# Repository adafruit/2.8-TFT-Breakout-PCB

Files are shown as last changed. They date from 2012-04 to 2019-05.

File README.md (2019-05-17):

# 2.8" TFT LCD Display Breakout PCBs
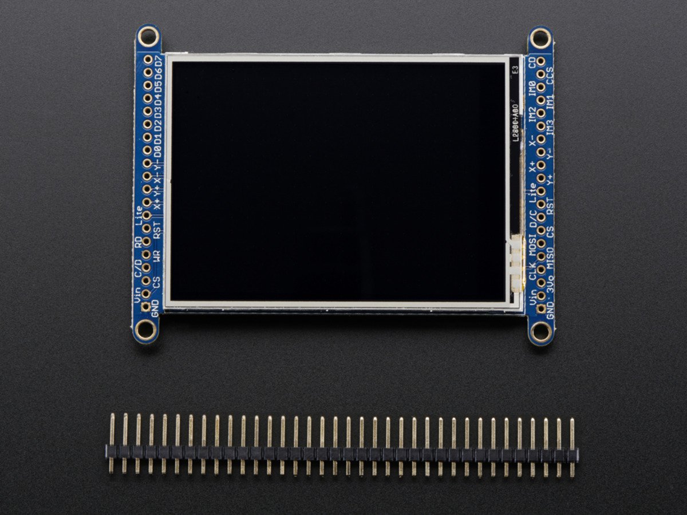
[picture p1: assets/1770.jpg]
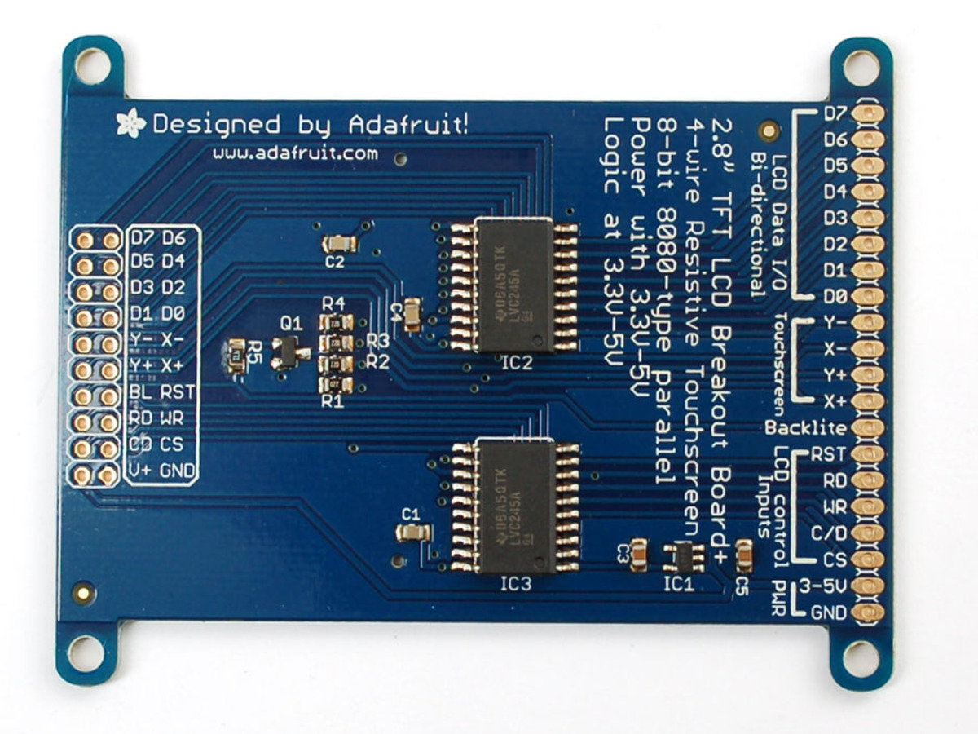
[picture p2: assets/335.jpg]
&nbsp; <br />
Click to view/purchase from the Adafruit Shop:
- [2.8" TFT LCD with Touchscreen Breakout Board w/MicroSD Socket - ILI9341](https://www.adafruit.com/product/1770)
- [2.8" 18-bit color TFT LCD with touchscreen breakout board - ILI9325](https://www.adafruit.com/product/335)

Add some jazz & pizazz to your project with a color touchscreen LCD. This TFT display is big (2.8" diagonal) bright (4 white-LED backlight) and colorful! 240x320 pixels with individual RGB pixel control, this has way more resolution than a black and white 128x64 display. As a bonus, this display has a resistive touchscreen attached to it already, so you can detect finger presses anywhere on the screen.

The ILI9325 screen has been discontinued, but the 2.8" ILI341 touchscreen breakout is nearly identical, having both an 8-bit and a SPI interface mode as well as a MicroSD card socket, all in the same form factor! 

Adafruit 2.8" 18-bit color TFT LCD displays with microSD card breakout

These are the Eagle CAD files for the Adafruit 2.8" 18-bit color TFT LCD display with microSD card breakouts:
  ----> https://www.adafruit.com/product/1770 (newer ILI9341 version)
  ----> https://www.adafruit.com/products/335 (older ILI9325 version)

### License

Adafruit invests time and resources providing this open source design, please support Adafruit and open-source hardware by [purchasing products from Adafruit](https://www.adafruit.com)!

All text above must be included in any redistribution

Designed by Limor Fried/Ladyada for Adafruit Industries.
Creative Commons Attribution/Share-Alike, all text above must be included in any redistribution. 
See license.txt for additional information.

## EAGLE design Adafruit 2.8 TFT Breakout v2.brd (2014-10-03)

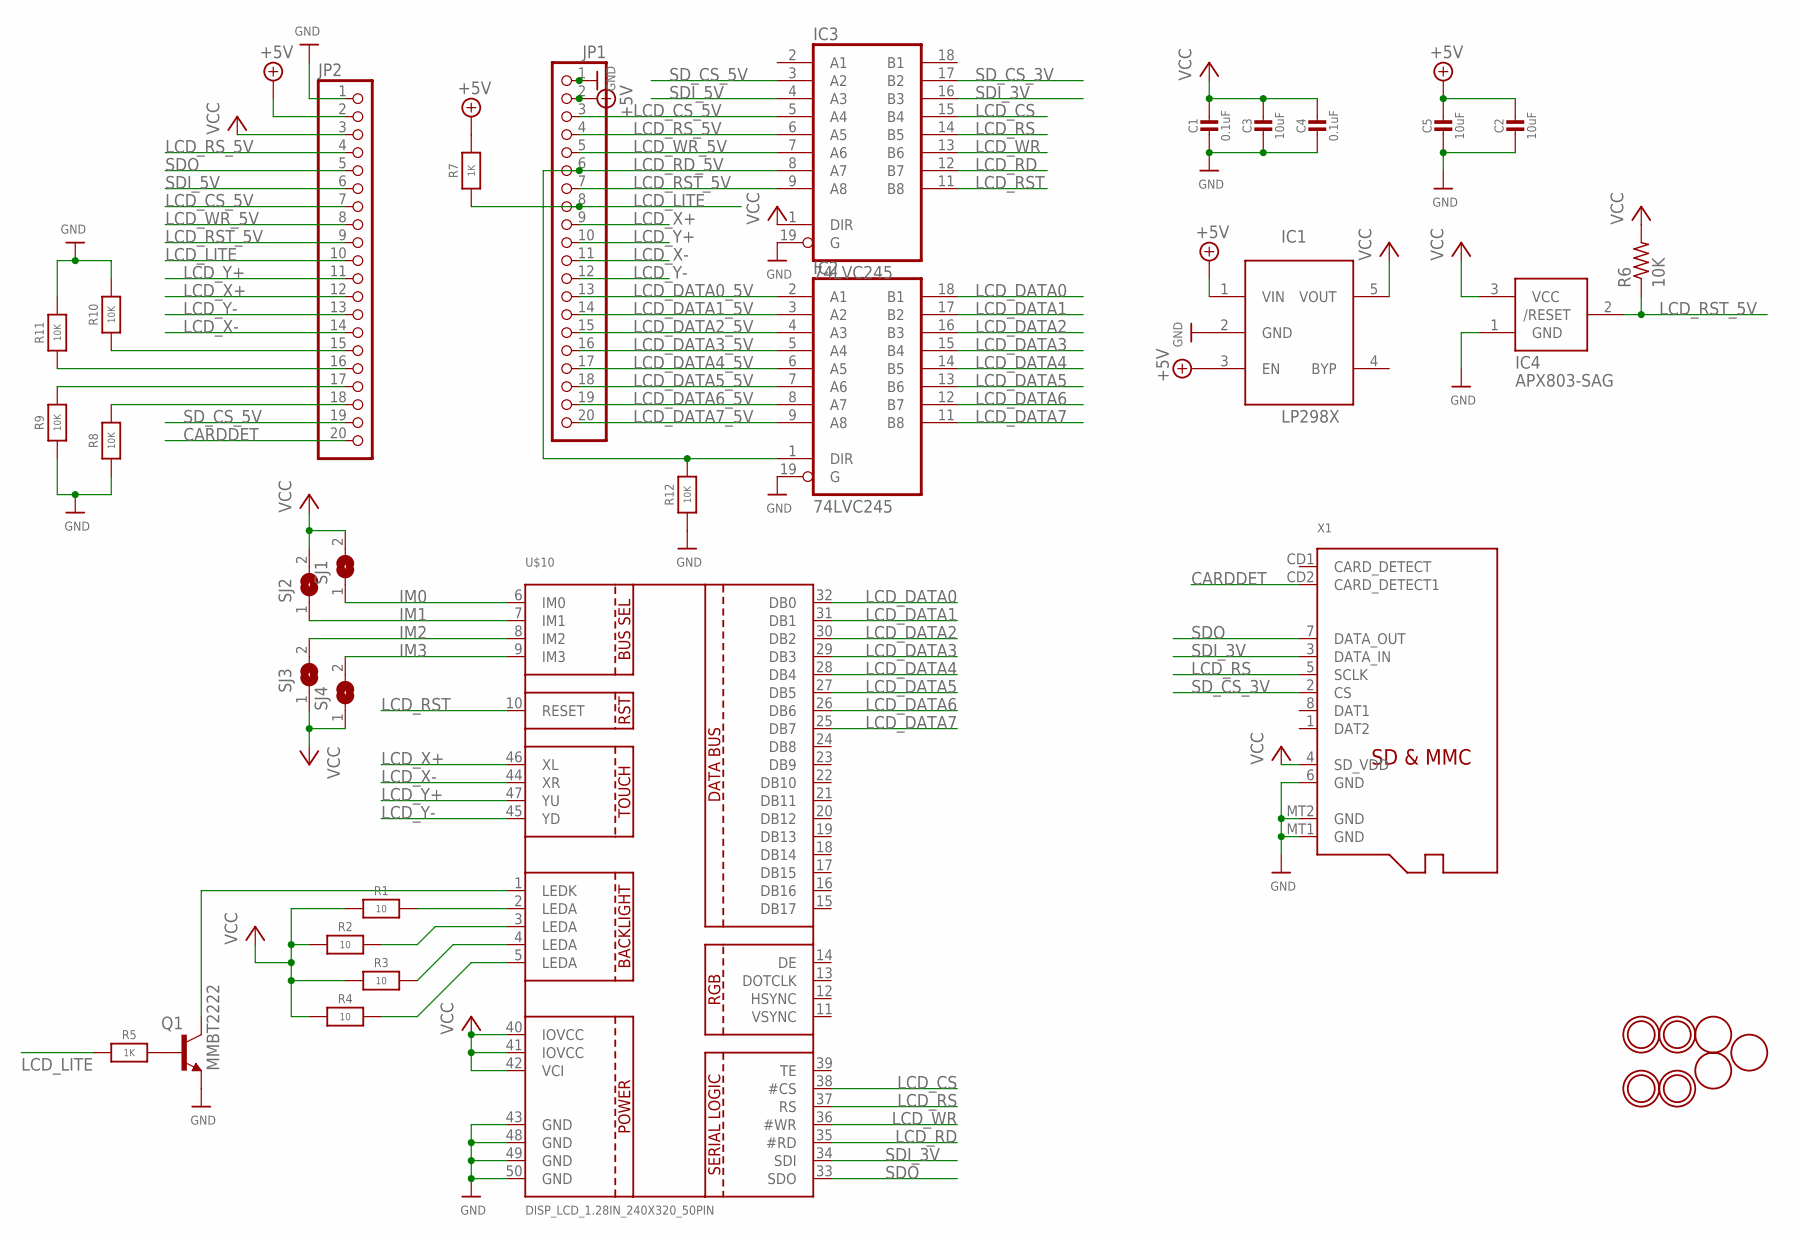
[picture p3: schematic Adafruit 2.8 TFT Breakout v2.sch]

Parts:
C1, C4: 0.1uF; 0805-NO
C2, C3, C5: 10uF; 0805-NO
IC1: MIC5225-3.3; SOT23-5L
IC2, IC3: 74LVC245; SO20W
IC4: APX803-SAG; SOT23
JP1, JP2: HEADER-1X20ROUND; 1X20_ROUND
Q1: MMBT2222; SOT23-BEC
R1, R2, R3, R4: 10; 0805-NO
R5, R7: 1K; 0805-NO
R6: 10K; R0805
R8, R9, R10, R11, R12: 10K; 0805-NO
SJ1, SJ2, SJ3, SJ4: SOLDERJUMPER; SOLDERJUMPER_ARROW_NOPASTE
U$7, U$15, U$16, U$17: MOUNTINGHOLE3.0THIN; MOUNTINGHOLE_3.0_PLATEDTHIN
U$9, U$11, U$23: FIDUCIAL; FIDUCIAL_1MM
U$10: DISP_LCD_1.28IN_240X320_50PIN; TFT_2.83IN_240X320_50PIN
X1: MICROSD

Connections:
+5V: C2.1, C5.1, IC1.1 (VIN), IC1.3 (EN), JP1.2, JP2.2, R7.2
CARDDET: JP2.20, X1.CD2 (CARD_DETECT1)
GND: C1.2, C2.2, C3.2, C4.2, C5.2, IC1.2 (GND), IC2.10 (GND), IC2.19 (G), IC3.10 (GND), IC3.19 (G), IC4.1 (GND), JP1.1, JP2.1, Q1.E, R8.1, R9.1, R10.2, R11.2, R12.1, U$10.43 (GND), U$10.48 (GND), U$10.49 (GND), U$10.50 (GND), X1.6 (GND), X1.MT1 (GND), X1.MT2 (GND)
IM0: JP2.18, R8.2, SJ1.1, U$10.6 (IM0)
IM1: JP2.17, R9.2, SJ2.1, U$10.7 (IM1)
IM2: JP2.16, R11.1, SJ3.2, U$10.8 (IM2)
IM3: JP2.15, R10.1, SJ4.2, U$10.9 (IM3)
LCD_CS: IC3.15 (B4), U$10.38 (#CS)
LCD_CS_5V: IC3.5 (A4), JP1.3, JP2.7
LCD_DATA0: IC2.18 (B1), U$10.32 (DB0)
LCD_DATA0_5V: IC2.2 (A1), JP1.13
LCD_DATA1: IC2.17 (B2), U$10.31 (DB1)
LCD_DATA1_5V: IC2.3 (A2), JP1.14
LCD_DATA2: IC2.16 (B3), U$10.30 (DB2)
LCD_DATA2_5V: IC2.4 (A3), JP1.15
LCD_DATA3: IC2.15 (B4), U$10.29 (DB3)
LCD_DATA3_5V: IC2.5 (A4), JP1.16
LCD_DATA4: IC2.14 (B5), U$10.28 (DB4)
LCD_DATA4_5V: IC2.6 (A5), JP1.17
LCD_DATA5: IC2.13 (B6), U$10.27 (DB5)
LCD_DATA5_5V: IC2.7 (A6), JP1.18
LCD_DATA6: IC2.12 (B7), U$10.26 (DB6)
LCD_DATA6_5V: IC2.8 (A7), JP1.19
LCD_DATA7: IC2.11 (B8), U$10.25 (DB7)
LCD_DATA7_5V: IC2.9 (A8), JP1.20
LCD_LITE: JP1.8, JP2.10, R5.1, R7.1
LCD_RD: IC3.12 (B7), U$10.35 (#RD)
LCD_RD_5V: IC2.1 (DIR), IC3.8 (A7), JP1.6, R12.2
LCD_RS: IC3.14 (B5), U$10.37 (RS), X1.5 (SCLK)
LCD_RST: IC3.11 (B8), U$10.10 (RESET)
LCD_RST_5V: IC3.9 (A8), IC4.2 (/RESET), JP1.7, JP2.9, R6.1
LCD_RS_5V: IC3.6 (A5), JP1.4, JP2.4
LCD_WR: IC3.13 (B6), U$10.36 (#WR)
LCD_WR_5V: IC3.7 (A6), JP1.5, JP2.8
LCD_X+: JP1.9, JP2.12, U$10.46 (XL)
LCD_X-: JP1.11, JP2.14, U$10.44 (XR)
LCD_Y+: JP1.10, JP2.11, U$10.47 (YU)
LCD_Y-: JP1.12, JP2.13, U$10.45 (YD)
unnamed: R4.2, U$10.5 (LEDA)
unnamed: R1.2, U$10.2 (LEDA)
unnamed: R2.2, U$10.3 (LEDA)
unnamed: R3.2, U$10.4 (LEDA)
unnamed: Q1.C, U$10.1 (LEDK)
unnamed: Q1.B, R5.2
SDI_3V: IC3.16 (B3), U$10.34 (SDI), X1.3 (DATA_IN)
SDI_5V: IC3.4 (A3), JP2.6
SDO: JP2.5, U$10.33 (SDO), X1.7 (DATA_OUT)
SD_CS_3V: IC3.17 (B2), X1.2 (CS)
SD_CS_5V: IC3.3 (A2), JP2.19
VCC: C1.1, C3.1, C4.1, IC1.5 (VOUT), IC2.20 (VCC), IC3.1 (DIR), IC3.20 (VCC), IC4.3 (VCC), JP2.3, R1.1, R2.1, R3.1, R4.1, R6.2, SJ1.2, SJ2.2, SJ3.1, SJ4.1, U$10.40 (IOVCC), U$10.41 (IOVCC), U$10.42 (VCI), X1.4 (SD_VDD)

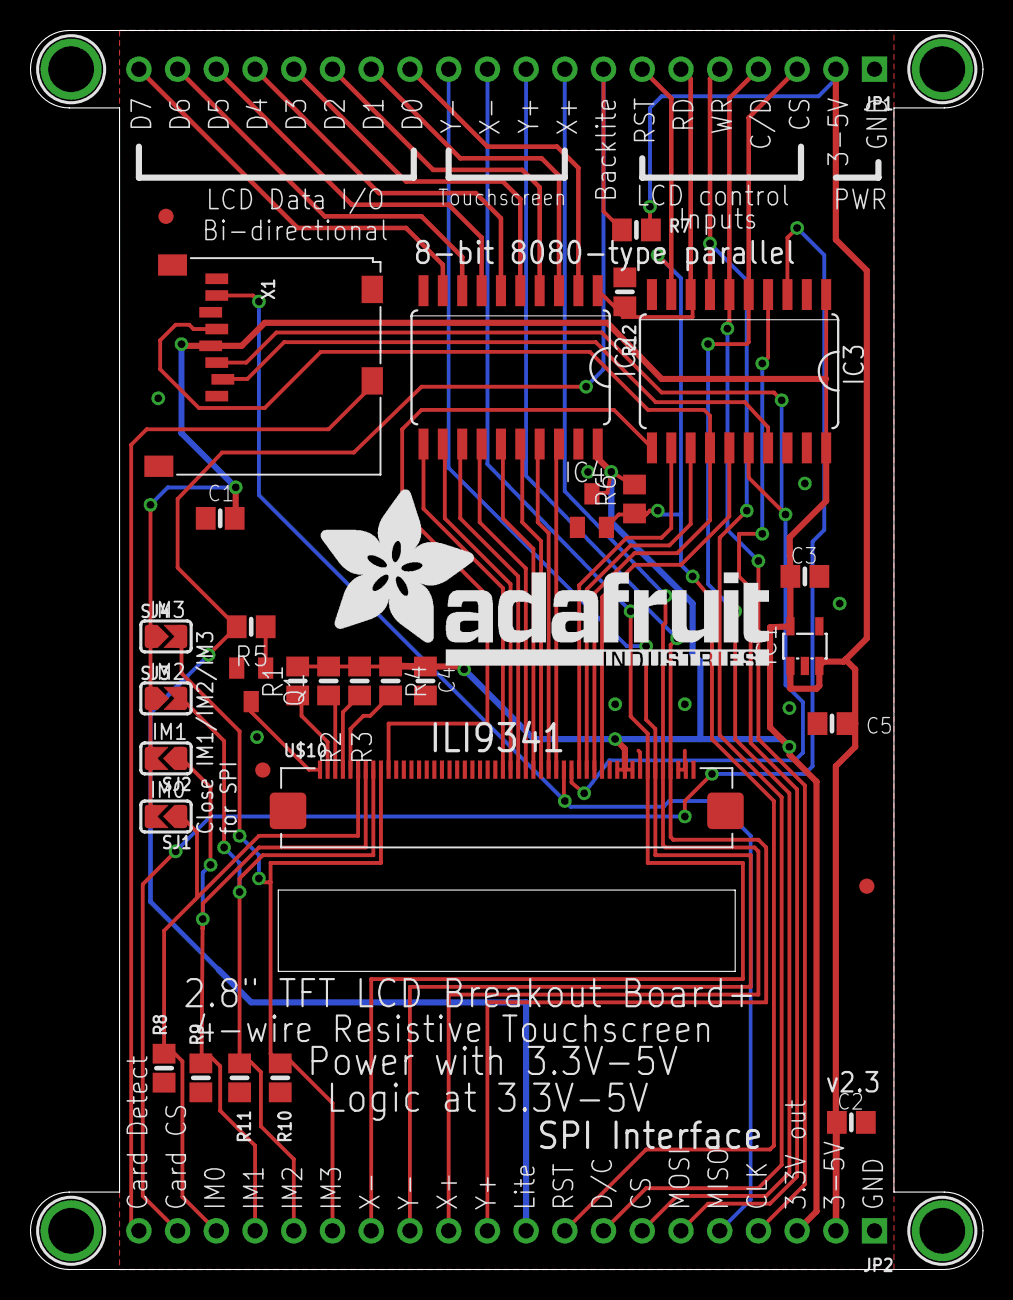
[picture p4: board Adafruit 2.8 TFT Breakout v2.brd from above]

Board: 2 copper layers, 62.5 x 81.3 mm, 38 parts (1 on the bottom side), 50 nets.

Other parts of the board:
U$19: ADAFRUIT_TEXT_30MM

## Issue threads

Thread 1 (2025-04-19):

Please post the EYESPI version of the eagle files.

DamageMosfet, 2025-04-19:
Please post the eagle files for the version with the EYESPI connector.  I was trying to see if the 2 GPIO pins were broken out to pads on the display.  The display might not need them, but I was going to use the flat cable to send the RX.TX lines to a different area of the circuit for use elsewhere.  I have 2 box halves with the feather/eyespi breakout on the bottom and the TFT on the top. I also have a GPS module int he top side.  I was going to locally run wires from the TFT to the GPS so that I don't have to run additional wires from the box bottom and box top.

It may not be possible, but I need to see the latest layout/schematic to see how pins supported by "EYESPI" butnot needed by the display are handled to know if I can repurpose/make use of them.

Per the adafruit Product Page...
"As of December 2, 2022 - we've updated this TFT breakout with an EYESPI connector to make cabling easier with an 18-pin FPC. We also used [Adafruit Pinguin](https://github.com/adafruit/Adafruit_Pinguin) to make a lovely silkscreen. The board is otherwise the same size, pinout, and functionality."

This update is not reflected in the source files or the schematics posted on the tutorial page.

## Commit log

2012-04-19 Eagle Cad files!
    [Adafruit_tftlcd8bit.brd, Adafruit_tftlcd8bit.sch]
2014-10-03 new v2 + readme
    [Adafruit 2.8 TFT Breakout v2.brd, Adafruit 2.8 TFT Breakout v2.sch]
